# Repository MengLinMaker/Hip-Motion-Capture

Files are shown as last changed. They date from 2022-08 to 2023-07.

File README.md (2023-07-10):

<h1 align="center"> Hip Motion Capture - <a href="https://menglinmaker-hip-motion-capture.netlify.app/">Demo</a></h1>

<div align="center">
  
</div>

## Aims
* To provide additional information for diagnosing fall injuries and identify preventions.
* To allow data scientists to collect labelled data and train better fall detection algorithms.

<div>&nbsp</div>

<div flex align="center">



</div>

Basic hip motion visualiser based on the [IMU-Webserial-Visualiser](https://github.com/MengLinMaker/IMU-Webserial-Visualiser). A total of three quaternions are used to represent orientations for the hip and two thighs. Capable of record accelerometer, gyroscope, magnetometer and quaternion data simultaneously at a rate of 120hz.

Made using [Three.js](https://threejs.org/), which is a WebGL wrapper, and the experimental Web Serial API. An ESP32 microctontroller interfaces with [FXOS8700 + FXAS21002](https://www.adafruit.com/product/3463), and two [BMX160](https://core-electronics.com.au/bmx160-9-axis-sensor-module-v1-0.html) IMUs and calculates the orientation using a [Madgwick Filter](https://ahrs.readthedocs.io/en/latest/filters/madgwick.html).
Finally the data is parsed into an array and streamed to the visualisation website.

<div>&nbsp</div><div>&nbsp</div><div>&nbsp</div><div>&nbsp</div><div>&nbsp</div>

## Requirements for usage

This demo requires a physical construction of the hip and thigh motion capture device. Placement of sensors are shown below:

<div align='center'>

</div>

Please contruct a similar or equivalent device to fully use this web visualiser.

<div>&nbsp</div>

## Instructions
**Live Visualisation Streaming**
1. Select baud rate.
2. Click connect and choose COM port.
**Recording Serial Data**
3. Choose buffer size for saving CSV (Optional).
4. Click save and enter file name to save (Optional).
Note: Choose a reasonable value for CSV buffer size: under 10^6.

<div align='center'>

</div>

<div>&nbsp</div><div>&nbsp</div><div>&nbsp</div><div>&nbsp</div><div>&nbsp</div>

# Development Process
The aim of this mini project is to create a physical device and visualise live motion data. Due to the complexity of the project, it is best approached by breaking the project into subsystems

Overall there are 3 major subsystems:
* Hardware: Physical device for strapping around waist and thigh, housing microcontroller and battery, plus interfacing with sensors.
* Firmware: Data collection and fusionto obtain quaternion orientations. The final data is then streamed to another ESP32 or strait to PC.
* Software: A website visualiser with data recording capabilities.

Since some parts between subsystems depend on each other, it is best to approach the project in different stages:
1. Create simple data stream from one sensor to website.
2. Develop a simple 3D visualisation to debug the orientation algorithm. Create a 3D printed housing for microcontroller and battery.
3. Integrate multiple sensors in hardware, firmware and software visualisation.

<div>&nbsp</div>

## Hardware
Since harware development is more risky, this is prioritised.
<div align='center'>

</div>

A battery is needed for the device for wireless transmission of data. Prototyping various charger designs determine the best dimensions for the battery case. This knowledge can also be applied to the device design.

<div align='center' flex>


</div>

A I2C sensor hub relays all the sensor data to the microcontroller. I2C reduces the number of wires needed and transfers data fast enough to reach over 100Hz samples from all three sensors. Flexible silicone prevents wire breakage.

<div align='center' flex>

</div>

Finally, the sensors need to be attached to the thigh and waist. Straps can secure the sensors, albeit with slipping issues. Pins can also be used to secure the placement of straps.

<div align='center' flex>

</div>

<div>&nbsp</div>

## Firmware
Data streaming is required for fast data collection and debugging. Wireless streaming is ideal since using wires could be hazardous during a fall, disconnect and suffer signal integrity issues. Madgwick filter is used to determine the orientation.

<div align='center'>

</div>

<div>&nbsp</div>

## Software
The website intefaces with serial USB using the webserial API. Three.js enables 3D visualisation. Overall, the software can be descibed in this block diagram.

<div align='center'>

</div>

<div>&nbsp</div><div>&nbsp</div><div>&nbsp</div><div>&nbsp</div><div>&nbsp</div>

# Credits
This code was modified from Mike Molinari's serialTerminal.com: https://github.com/mmiscool/serialTerminal.com
Reskinned UI and refactored the original code. Added ability to save CSV file and determine last full line, stored in "currentData".
Access the original webserial terminal here: https://www.serialterminal.com

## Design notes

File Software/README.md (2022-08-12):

# Hip Motion Capture- Software

Visualisation software using [Three.js](https://threejs.org/), which is a WebGL wrapper, and the experimental Web Serial API. Accepts a data stream consisting of gyroscope, accelerometer, magnetometer and quaternion for each sensor.

___
<h3 align="center"> ->> <a href="https://menglinmaker-hip-motion-capture.netlify.app/">Live Demo!</a> <<- </h3>

___

<div align='center'>

</div>

## Instructions
**Live Visualisation Streaming**
1. Select baud rate.
2. Click connect and choose COM port.
**Recording Serial Data**
3. Choose buffer size for saving CSV (Optional).
4. Click save and enter file name to save (Optional).
Note: Choose a reasonable value for CSV buffer size: under 10^6.

## Block Diagram
<div align='center'>

</div>

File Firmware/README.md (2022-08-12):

# Hip Motion Capture - Firmware
Data from all three IMUs are streamed to the ESP32 microcontroller. Then the orientation is calculated using a [Madgwick Filter](https://ahrs.readthedocs.io/en/latest/filters/madgwick.html). Finally the data is parsed into an array and streamed to the visualisation website.

Since data streaming is required for fast data collection and debugging. Wireless streaming is ideal since using wires could be hazardous during a fall, disconnect and suffer signal integrity issues. [The final solution is to use ESP-NOW for data streaming.](https://github.com/MengLinMaker/ESP32-data-stream-comparisons)

<div align='center'>

</div>

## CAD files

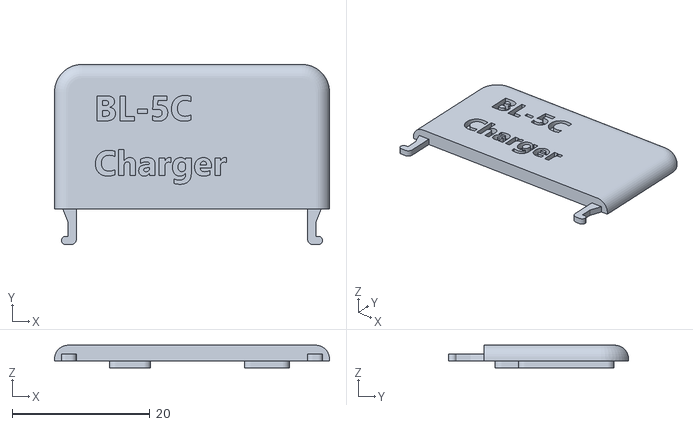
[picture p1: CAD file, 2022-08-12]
Hardware/Charger STL/top case.STL
40.0 x 26.2 x 3.30

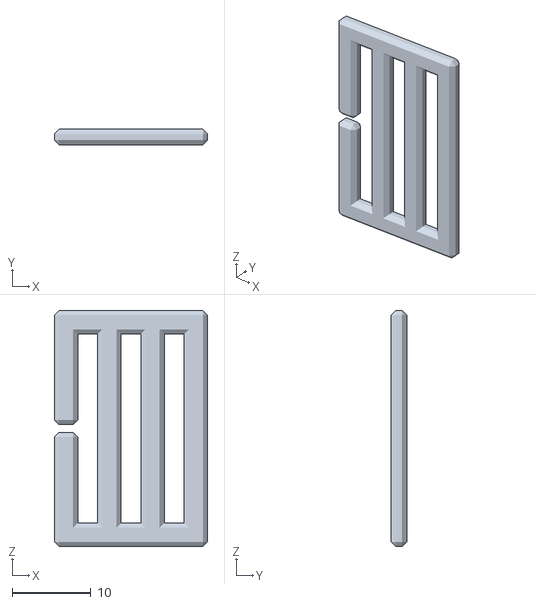
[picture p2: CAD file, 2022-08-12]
Hardware/Strap Clips STL/25mm strap clip.STL
19.5 x 2.00 x 30.0

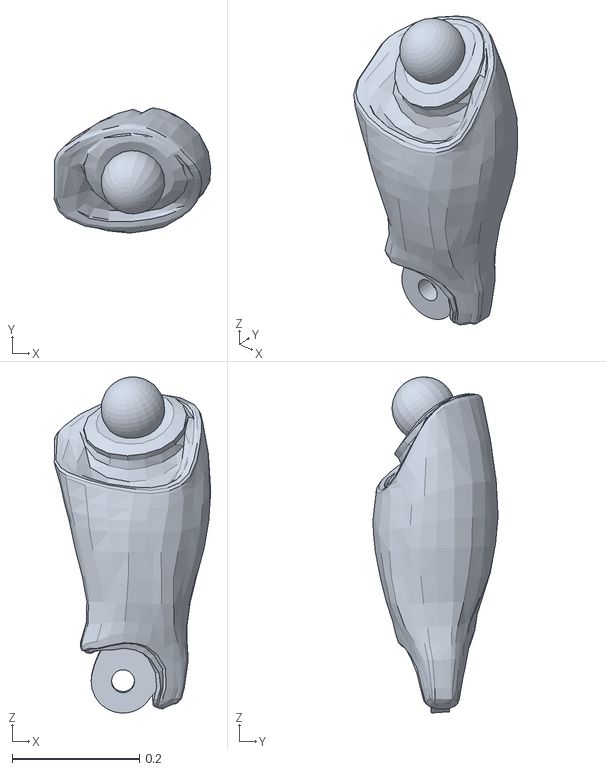
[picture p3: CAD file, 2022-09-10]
Software/asset/LeftThigh.stl
0.246 x 0.197 x 0.528

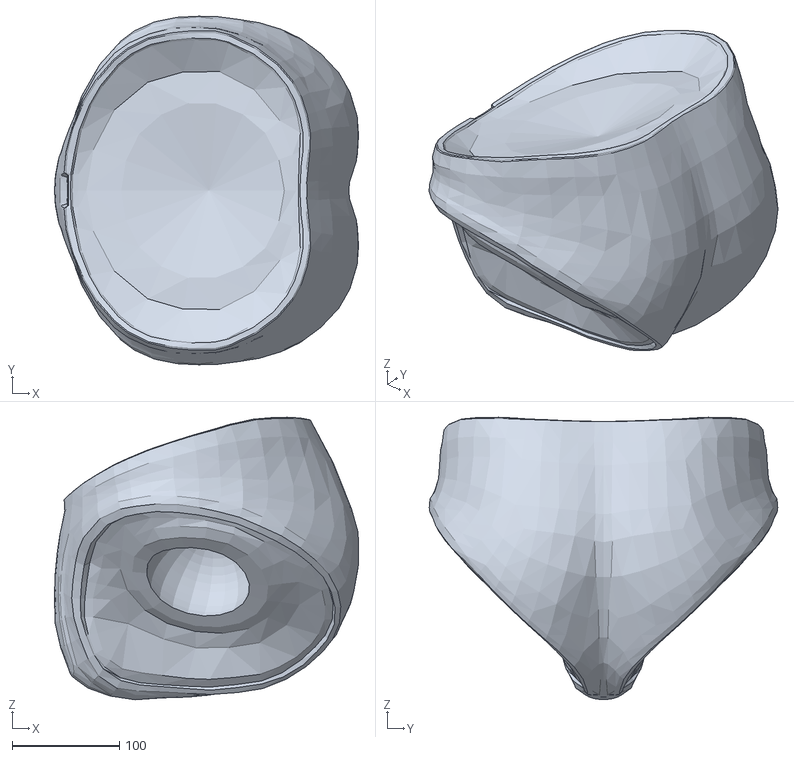
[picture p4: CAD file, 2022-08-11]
Software/dist/assets/hip.6fd1d9b4.stl
282.9 x 324.4 x 262.9

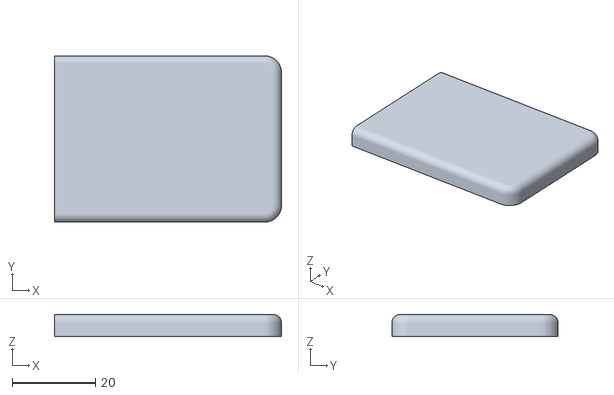
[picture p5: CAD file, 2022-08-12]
Hardware/Charger STL/lid.STL
54.6 x 40.0 x 5.30

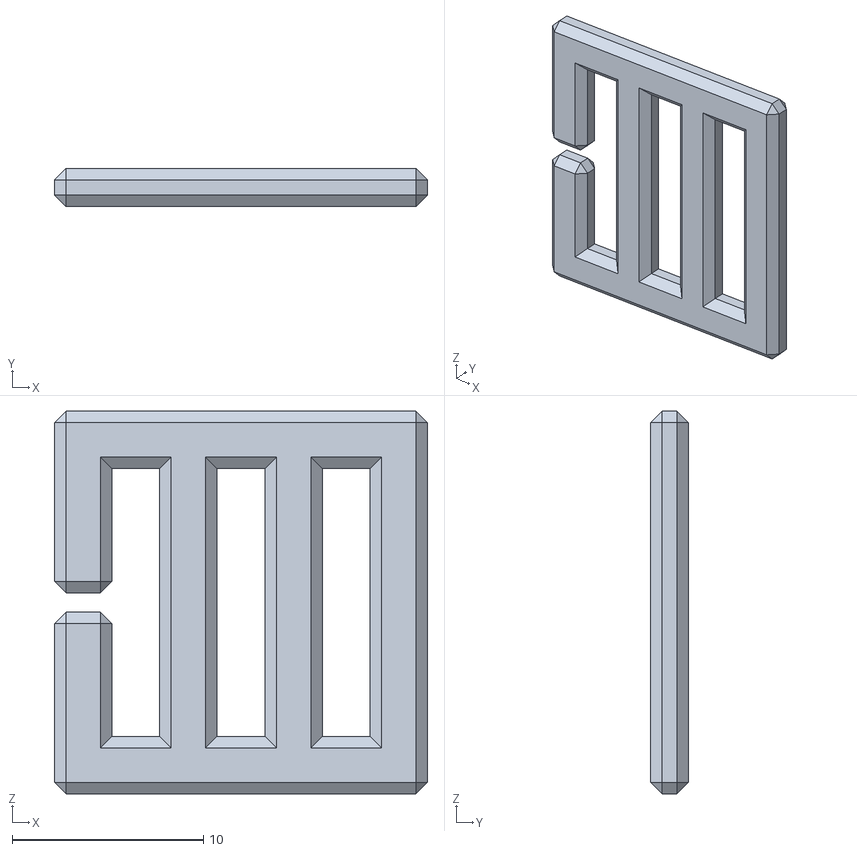
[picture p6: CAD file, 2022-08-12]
Hardware/Strap Clips STL/15mm strap clip.STL
19.5 x 2.00 x 20.0

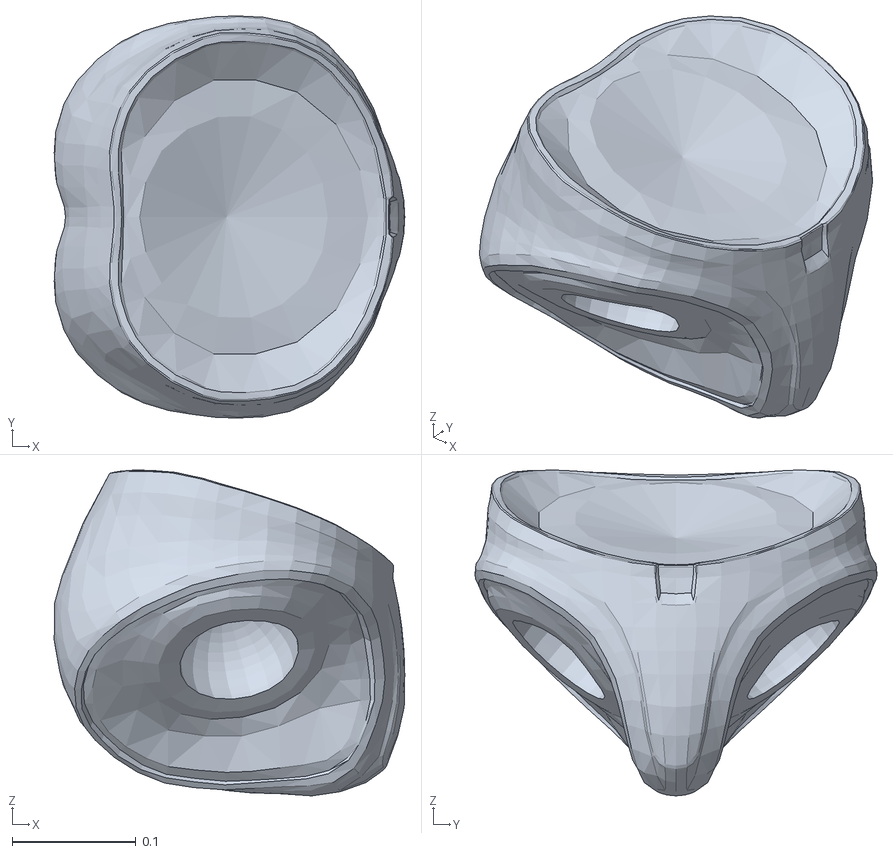
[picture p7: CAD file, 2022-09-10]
Software/asset/hip.stl
0.283 x 0.324 x 0.263

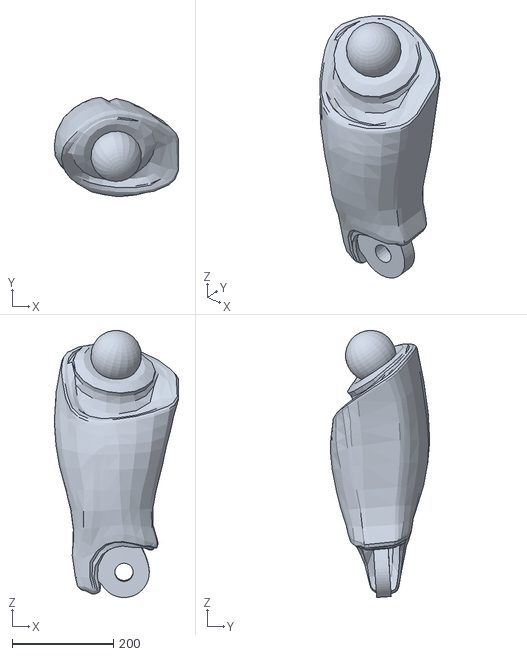
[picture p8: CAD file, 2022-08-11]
Software/dist/assets/rightThigh.6f7f5b74.stl
246.0 x 196.7 x 528.0

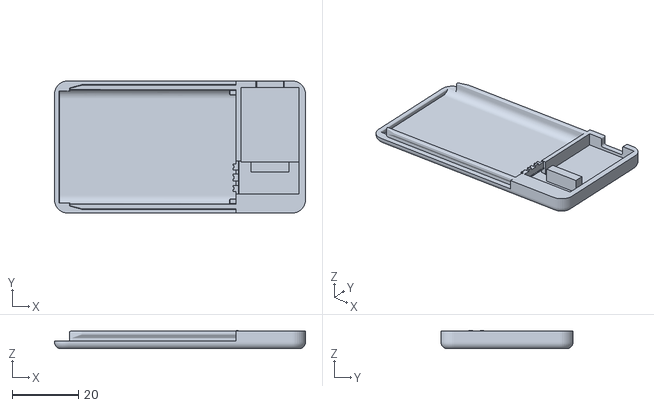
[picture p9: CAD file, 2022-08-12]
Hardware/Charger STL/bottom case.STL
76.0 x 40.0 x 5.60

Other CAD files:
Software/asset/rightThigh.stl

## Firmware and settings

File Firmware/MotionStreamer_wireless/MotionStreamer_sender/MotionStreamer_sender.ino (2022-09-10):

/*
  Testing communication with sensors
*/

#include "src/BodyModel/BodyModel.h"
#include "src/Communication/EspNow/esp_now_wrapper.h"

// REPLACE WITH YOUR RECEIVER MAC Address
uint8_t broadcastAddress[] = {0x30, 0xAE, 0xA4, 0x9B, 0xF5, 0x44};

// Change data rate
const long frequency = 50;
const long ideal_period = round(1000000.0/frequency);
static SemaphoreHandle_t timer_sem;

BodyModel model;





void sample_timer_task(void *param)
{
  timer_sem = xSemaphoreCreateBinary();
  while (1) {
    xSemaphoreTake(timer_sem, portMAX_DELAY);



    model.filter();
    float D[30];
    model.getFlattenedData(D);
    guaranteeSend(broadcastAddress, (uint8_t*) &D, sizeof(D));

    /*/ Printing data for debugging
    char string_buff[300];
    sprintf(string_buff, "%f,%f,%f,%f,%f,%f,%f,%f,%f,%f,%f,%f,%f,%f,%f,%f,%f,%f,%f,%f,%f,%f,%f,%f,%f,%f,%f,%f,%f,%f",
    D[0], D[1], D[2], D[3], D[4], D[5], D[6], D[7], D[8], D[9],
    D[10], D[11], D[12], D[13], D[14], D[15], D[16], D[17], D[18], D[19],
    D[20], D[21], D[22], D[23], D[24], D[25], D[26], D[27], D[28], D[29]);
    Serial.println(string_buff);
    //*/

    
  }
}

void IRAM_ATTR onTimer(){
  static BaseType_t xHigherPriorityTaskWoken = pdFALSE;
  xSemaphoreGiveFromISR(timer_sem, &xHigherPriorityTaskWoken);
  if( xHigherPriorityTaskWoken) {
    portYIELD_FROM_ISR(); // this wakes up sample_timer_task immediately
  }
}





void setup(){
  //Serial.begin(1000000);
  model.begin(frequency);
  setupEspNowReceiver(broadcastAddress);

  // Create timer interrupt
  hw_timer_t *ticker = NULL;
  ticker = timerBegin(0, 2, true);
  timerAttachInterrupt(ticker, onTimer, true);
  timerAlarmWrite(ticker, 40*ideal_period, true);
  timerAlarmEnable(ticker);

  xTaskCreatePinnedToCore(sample_timer_task, "sample_timer", 4096, NULL, configMAX_PRIORITIES - 1, NULL, 1);
}

void loop(){}

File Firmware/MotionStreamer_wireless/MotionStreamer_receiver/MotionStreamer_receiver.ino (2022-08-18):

/*
  Name: ESP NOW receiver with USB UART
  Purpose: Receives stream data from sender and sends it over USB UART to computer
  For catching
  Credits: Based off Rui Santos's ESP_NOW library: https://RandomNerdTutorials.com/esp-now-esp32-arduino-ide/
  @author Meng Lin
  @version 1.1 20/04/22
*/

#include "src/esp_now_wrapper.h"
#include <esp_wifi.h>

// REPLACE WITH YOUR RECEIVER MAC Address
// uint8_t broadcastAddress[] = {0x78, 0x21, 0x84, 0x88, 0xBB, 0x94};

// Receiver redefined MAC address
uint8_t newMACAddress[] = {0x30, 0xAE, 0xA4, 0x9B, 0xF5, 0x44};

float D[30];


void OnDataRec(const uint8_t *mac, const uint8_t *incomingData, int len){
  memcpy(&D, incomingData, sizeof(D));
  char string_buff[300];
  sprintf(string_buff, "%f,%f,%f,%f,%f,%f,%f,%f,%f,%f,%f,%f,%f,%f,%f,%f,%f,%f,%f,%f,%f,%f,%f,%f,%f,%f,%f,%f,%f,%f",
  D[0], D[1], D[2], D[3], D[4], D[5], D[6], D[7], D[8], D[9],
  D[10], D[11], D[12], D[13], D[14], D[15], D[16], D[17], D[18], D[19],
  D[20], D[21], D[22], D[23], D[24], D[25], D[26], D[27], D[28], D[29]);
  Serial.println(string_buff);
}





void setup(){
  Serial.begin(1000000);
  setupEspNowReceiver(OnDataRec);
  esp_wifi_set_mac(WIFI_IF_STA, &newMACAddress[0]);
} 

void loop(){}

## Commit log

2022-08-11 Modify for vite build and live demo
    [hip.stl, rightThigh.stl]
2022-08-12 Add Subsystem files
    [15mm strap clip.STL, 25mm strap clip.STL, bottom case.STL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]
2022-08-12 Move sofware to respective folder
    [hip.stl, rightThigh.stl]
2022-08-18 Override receiver MAC address for different ESP32
2022-08-20 Add new hip and thigh STL to asset
    [Hip.stl, LeftThigh.stl, RightThigh.stl]
2022-09-09 Add addition STL models
    [hip.stl, rightThigh.stl]
2022-09-09 Revert "Add addition STL models"
    This reverts commit 0cb8e1479fda890ee107b559a012117afde2beb2.
    [hip.stl, rightThigh.stl]
2022-09-09 Add Missing Hip and Thigh STL
    [hip.stl, rightThigh.stl]
2022-09-09 Revert "Add Missing Hip and Thigh STL"
    This reverts commit b4e241187d1ee19389d7835de6840f20393a8a1b.
    [hip.stl, rightThigh.stl]
2022-09-09 Revert "Revert "Add Missing Hip and Thigh STL""
    This reverts commit bad2d436666e52506c31ea97ac17dac515bbc198.
    [hip.stl, rightThigh.stl]
2022-09-09 Change STL
    [hip.6fd1d9b4.stl, rightThigh.6f7f5b74.stl]
2022-09-09 Update STL
    [hip.stl, rightThigh.stl]
2022-09-09 Remove STL
    [Hip.stl, RightThigh.stl, hip.stl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]
2022-09-09 Add working STL
    [hip.stl, rightThigh.stl]
2022-09-10 Add Auto Heading Calibration to Firmware
    [LeftThigh.stl, hip.stl, rightThigh.stl]
2022-09-10 Fixed Heading Callibration ESP32 ISR Float Bug
    [MotionStreamer_sender.ino]
2022-09-10 Lowered beta: rely more on gyro data for AHRS
